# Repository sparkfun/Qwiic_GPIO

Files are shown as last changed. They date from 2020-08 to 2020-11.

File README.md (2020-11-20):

SparkFun Qwiic GPIO
=======================================

SparkFun Qwiic GPIO (https://cdn.sparkfun.com/assets/parts/1/5/9/9/3/17047-SparkFun_Qwiic_GPIO-01.jpg)

[*SparkFun Qwiic GPIO (DEV-17047)*](https://www.sparkfun.com/products/17047)

TCA9534 breakout board with Qwiic connectors and easy-to-use latch terminals; no longer screw wires into place! Use this board to add more GPIO pins to your system.

Repository Contents
-------------------

* **/Documents** - Contains datasheets and schematic.pdf
* **/Hardware** - Current .brd and .sch files for product
* **/Production** - Production panel files (.brd)

Documentation
-------------

* **[Hookup Guide](https://learn.sparkfun.com/tutorials/sparkfun-qwiic-gpio-hookup-guide)** - Hookup guide for The SparkFun Qwiic GPIO.
* **[Datasheet](https://cdn.sparkfun.com/assets/b/b/f/1/7/TCA9534.pdf) (TCA9534)** - Datasheet for the TCA9534.
* **[Qwiic Resource Page](https://www.sparkfun.com/qwiic)** - Resource guide for Qwiic.
* **[Arduino Library](https://github.com/sparkfun/SparkFun_Qwiic_GPIO_Library)** - Arduino Library for the SparkFun Qwiic GPIO.
* **[Python Package](https://github.com/sparkfun/Qwiic_GPIO_Py)** - Python package
* **[GitHub Hardware Repo](https://github.com/sparkfun/Qwiic_GPIO)** - Github Hardware Repo

License Information
-------------------

This product is _**open source**_!

Please review the LICENSE.md file for license information.

If you have any questions or concerns on licensing, please contact technical support on our [SparkFun forums](https://forum.sparkfun.com/viewforum.php?f=152).

Distributed as-is; no warranty is given.

- Your friends at SparkFun._

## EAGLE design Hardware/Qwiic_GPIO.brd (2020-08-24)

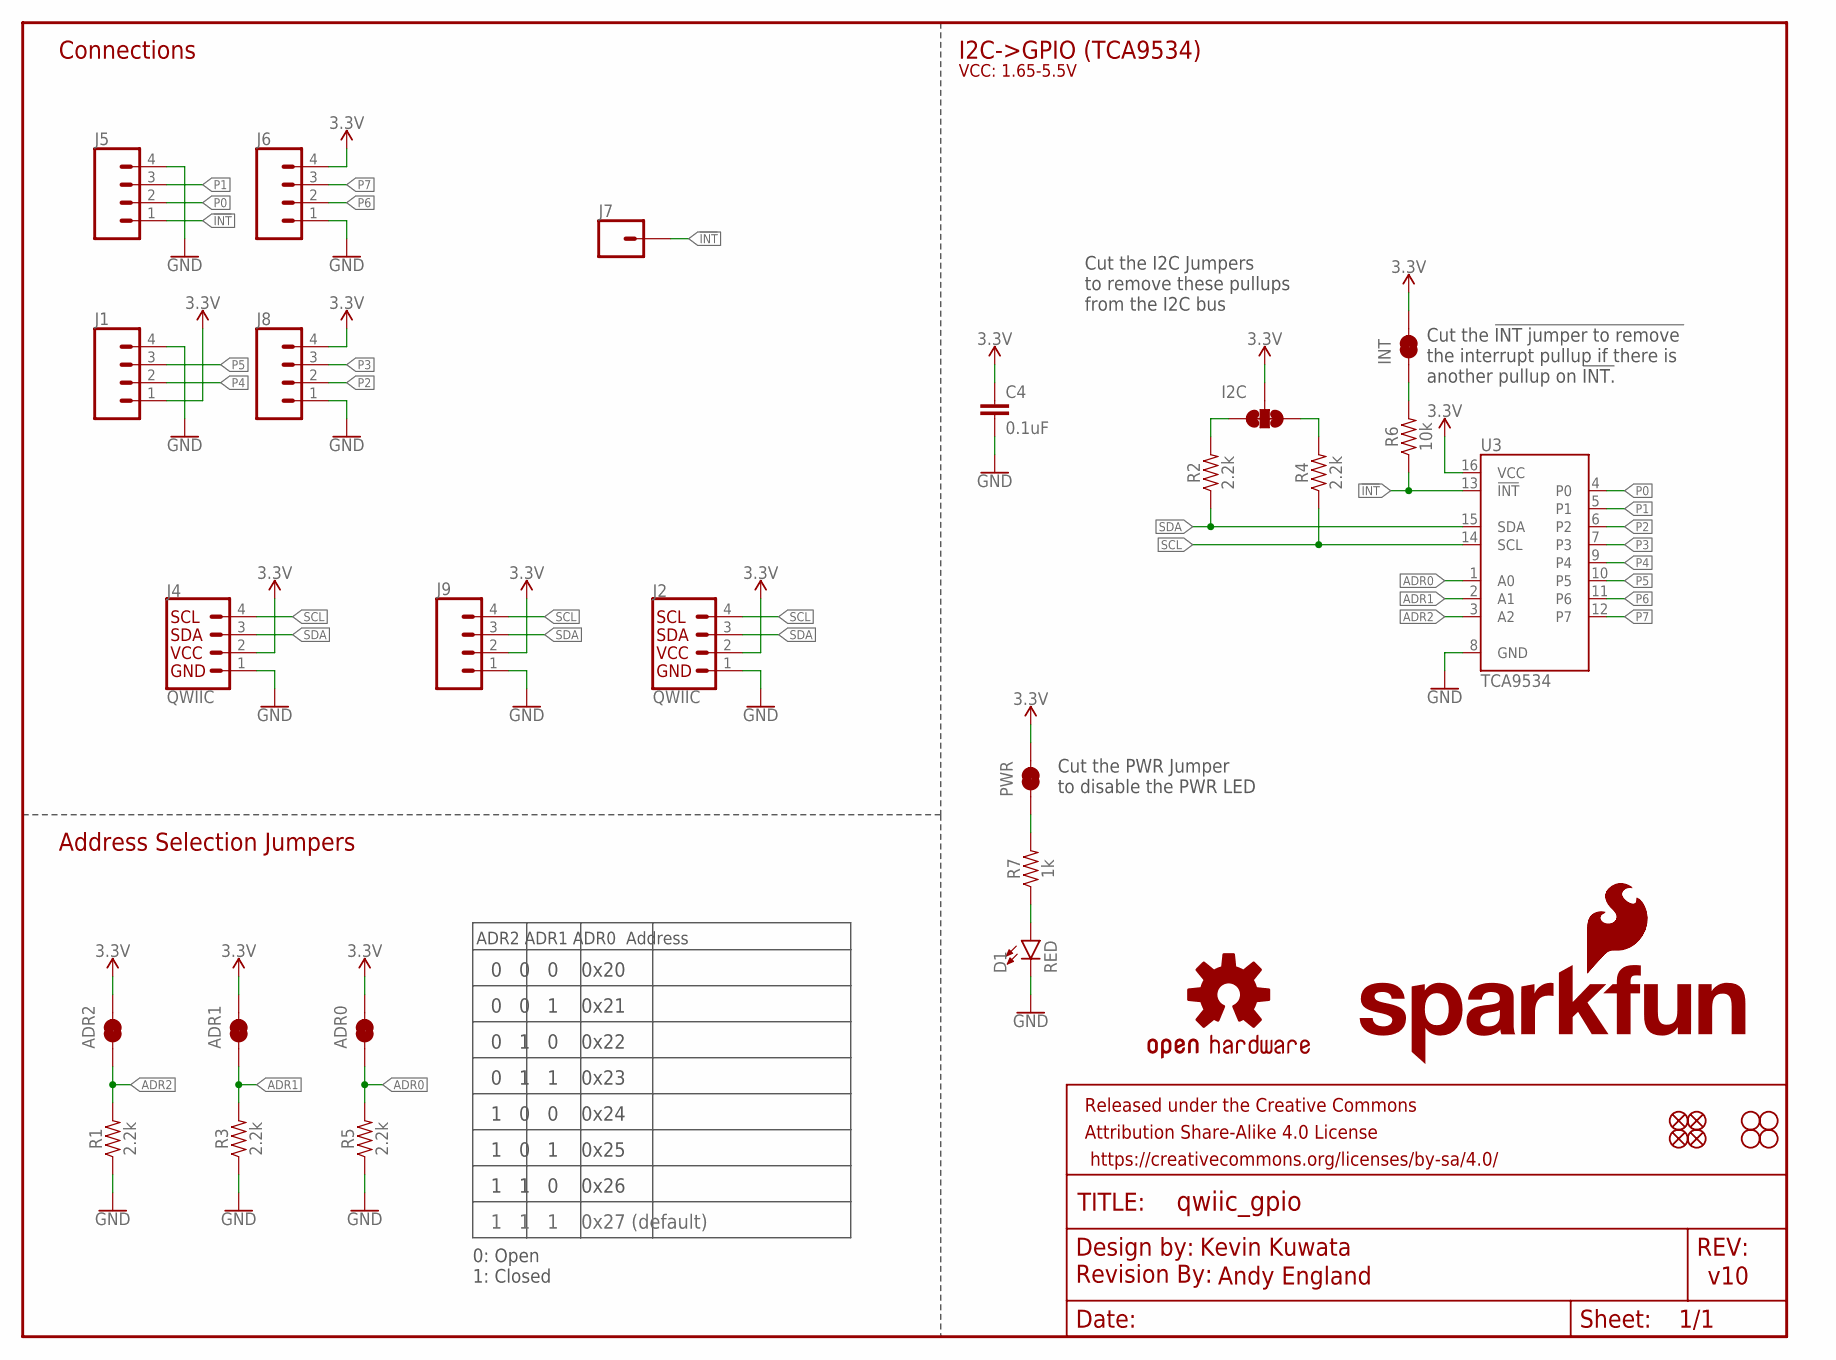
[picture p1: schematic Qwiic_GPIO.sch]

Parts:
ADR0, ADR1, ADR2: JUMPER-SMT_2_NC_TRACE_SILK; SMT-JUMPER_2_NC_TRACE_SILK
C4: 0.1uF; 0603
D1: RED; LED-0603
FD1, FD2: FIDUCIAL1X2; FIDUCIAL-1X2
FRAME1: FRAME-LETTER; CREATIVE_COMMONS
H1, H2: STAND-OFF
I2C: JUMPER-SMT_3_2-NC_TRACE_SILK; SMT-JUMPER_3_2-NC_TRACE_SILK
INT: JUMPER-SMT_2_NC_TRACE_SILK; SMT-JUMPER_2_NC_TRACE_SILK
J1, J5, J6, J8: CONN_04LATCH; LATCHTERMINAL-5MM-4
J2, J4: QWIIC; JST04_1MM_RA
J7: CONN_01PTH_NO_SILK_YES_STOP; 1X01_NO_SILK
J9: CONN_041X04_NO_SILK; 1X04_NO_SILK
JP2, JP6: FIDUCIAL1X2; FIDUCIAL-1X2
JP3, JP4: STAND-OFF
LOGO1: OSHW-LOGOMINI; OSHW-LOGO-MINI
LOGO2: REVISION
LOGO3: SFE_LOGO_NAME_FLAME.1_INCH; SFE_LOGO_NAME_FLAME_.1
LOGO4: SFE_LOGO_FLAME.2_INCH; SFE_LOGO_FLAME_.2
PWR: JUMPER-SMT_2_NC_TRACE_SILK; SMT-JUMPER_2_NC_TRACE_SILK
R1, R2, R3, R4, R5: 2.2k; 0603
R6: 10k; 0603
R7: 1k; 0603
U3: TCA9534; 16SOIC

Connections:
3.3V: ADR0.2, ADR1.2, ADR2.2, C4.1, I2C.2, INT.2, J1.1, J2.2, J4.2, J6.4, J8.4, J9.2, PWR.2, U3.16 (VCC)
!INT: J5.1, J7.1, R6.1, U3.13 (!INT)
ADR0: ADR0.1, R5.2, U3.1 (A0)
ADR1: ADR1.1, R3.2, U3.2 (A1)
ADR2: ADR2.1, R1.2, U3.3 (A2)
GND: C4.2, D1.C, J1.4, J2.1, J4.1, J5.4, J6.1, J8.1, J9.1, R1.1, R3.1, R5.1, U3.8 (GND)
unnamed: INT.1, R6.2
unnamed: D1.A, R7.1
unnamed: PWR.1, R7.2
P0: J5.2, U3.4 (P0)
P1: J5.3, U3.5 (P1)
P2: J8.2, U3.6 (P2)
P3: J8.3, U3.7 (P3)
P4: J1.2, U3.9 (P4)
P5: J1.3, U3.10 (P5)
P6: J6.2, U3.11 (P6)
P7: J6.3, U3.12 (P7)
SCL: J2.4, J4.4, J9.4, R4.1, U3.14 (SCL)
SCL_PU1: I2C.1, R2.2
SDA: J2.3, J4.3, J9.3, R2.1, U3.15 (SDA)
SDA_PU1: I2C.3, R4.2

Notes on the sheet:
Kevin Kuwata
v10
Address Selection Jumpers
ADR2 ADR1 ADR0 Address
0 0 0 0x20
0 0 1 0x21
0 1 0 0x22
0 1 1 0x23
1 0 0 0x24
1 0 1 0x25
1 1 0 0x26
1 1 1 0x27 (default)
0: Open 1: Closed
I2C->GPIO (TCA9534)
Connections
VCC: 1.65-5.5V
Andy England
Cut the !INT jumper to remove the interrupt pullup if there is another pullup on !INT.
Cut the I2C Jumpers to remove these pullups from the I2C bus
Cut the PWR Jumper to disable the PWR LED

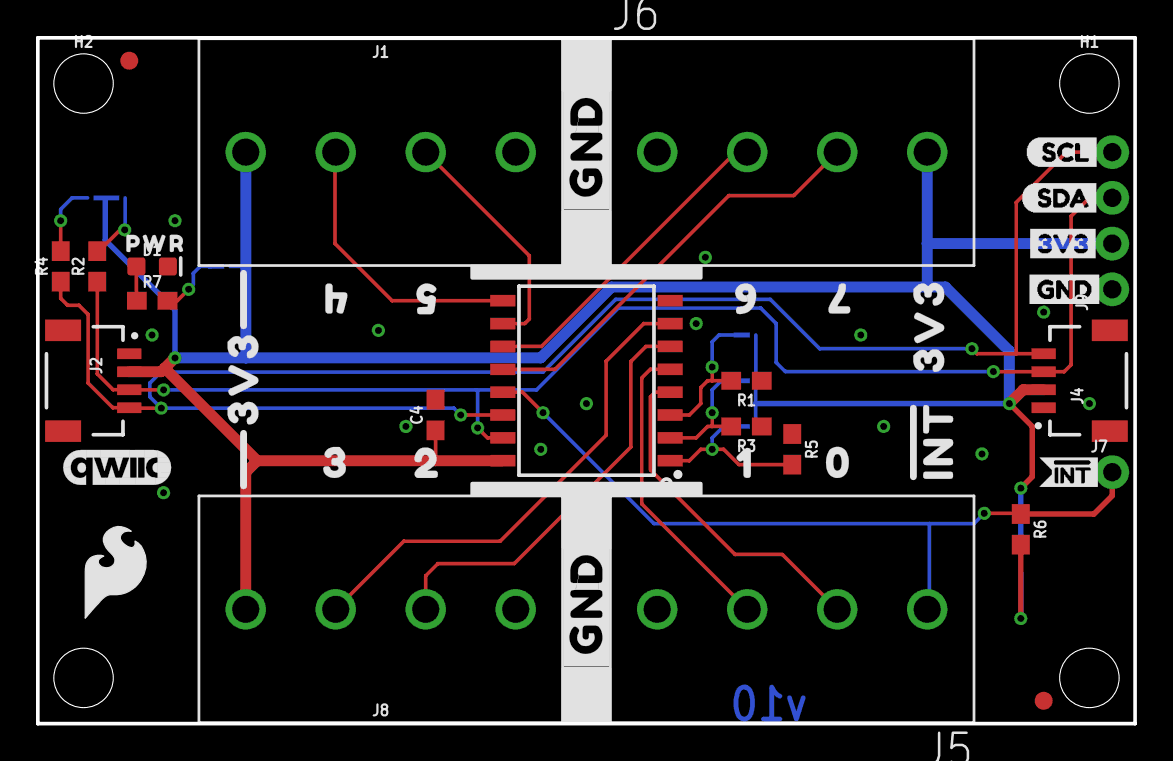
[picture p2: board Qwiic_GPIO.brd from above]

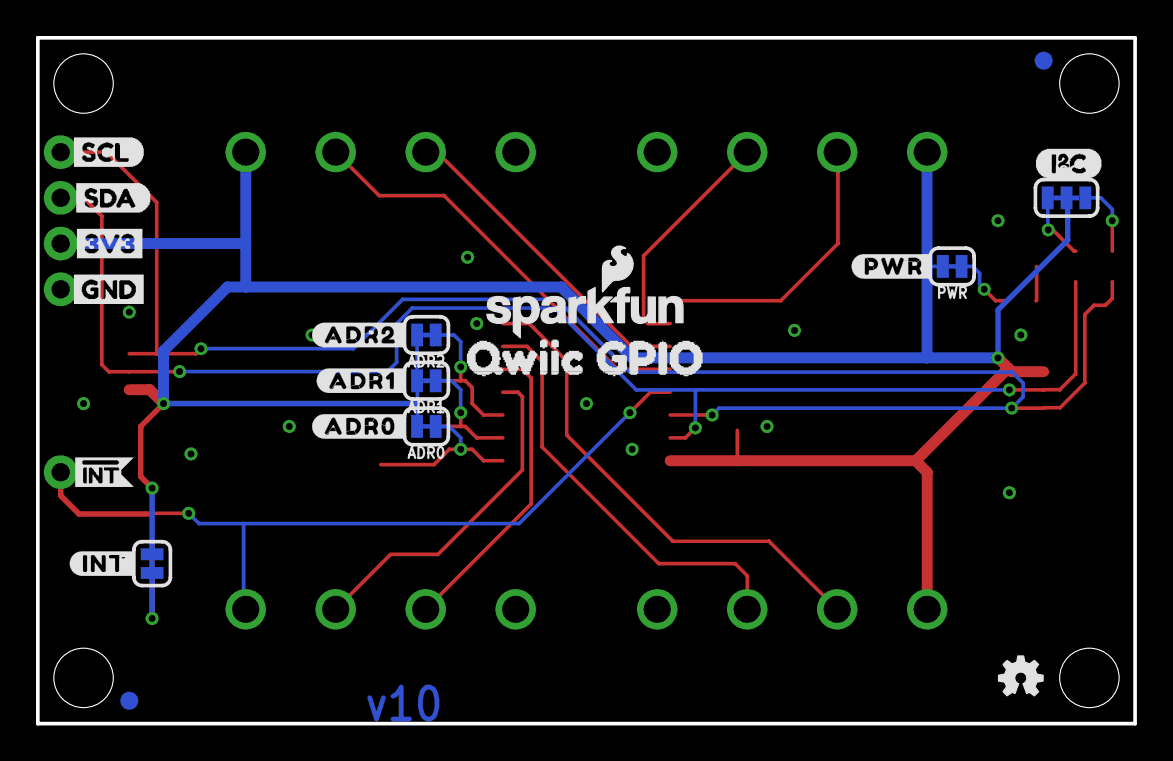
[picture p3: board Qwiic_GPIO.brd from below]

Board: 2 copper layers, 61.0 x 38.1 mm, 69 parts (22 on the bottom side), 21 nets.

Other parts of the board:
U$1: I2C
U$2: 20
U$3, U$26: 3V33
U$4: 30
U$5: #ADR1#0
U$6: 10
U$7, U$25: GND4
U$8: QWIIC_GPIO7
U$9: SCL6
U$10: SDA5
U$11: #ADR2#0
U$12: #INT#0
U$13, U$22, U$29: #INT0
U$14: 00
U$15: #ADR0#0
U$21: QWIIC_6MM
U$23: SCL0
U$24: SDA1
U$30, U$31: 3V30
U$32: 40
U$33: 50
U$34: PWR0
U$35: 60
U$37: 70
U$38, U$40: #GND#0
U$39: #PWR#0

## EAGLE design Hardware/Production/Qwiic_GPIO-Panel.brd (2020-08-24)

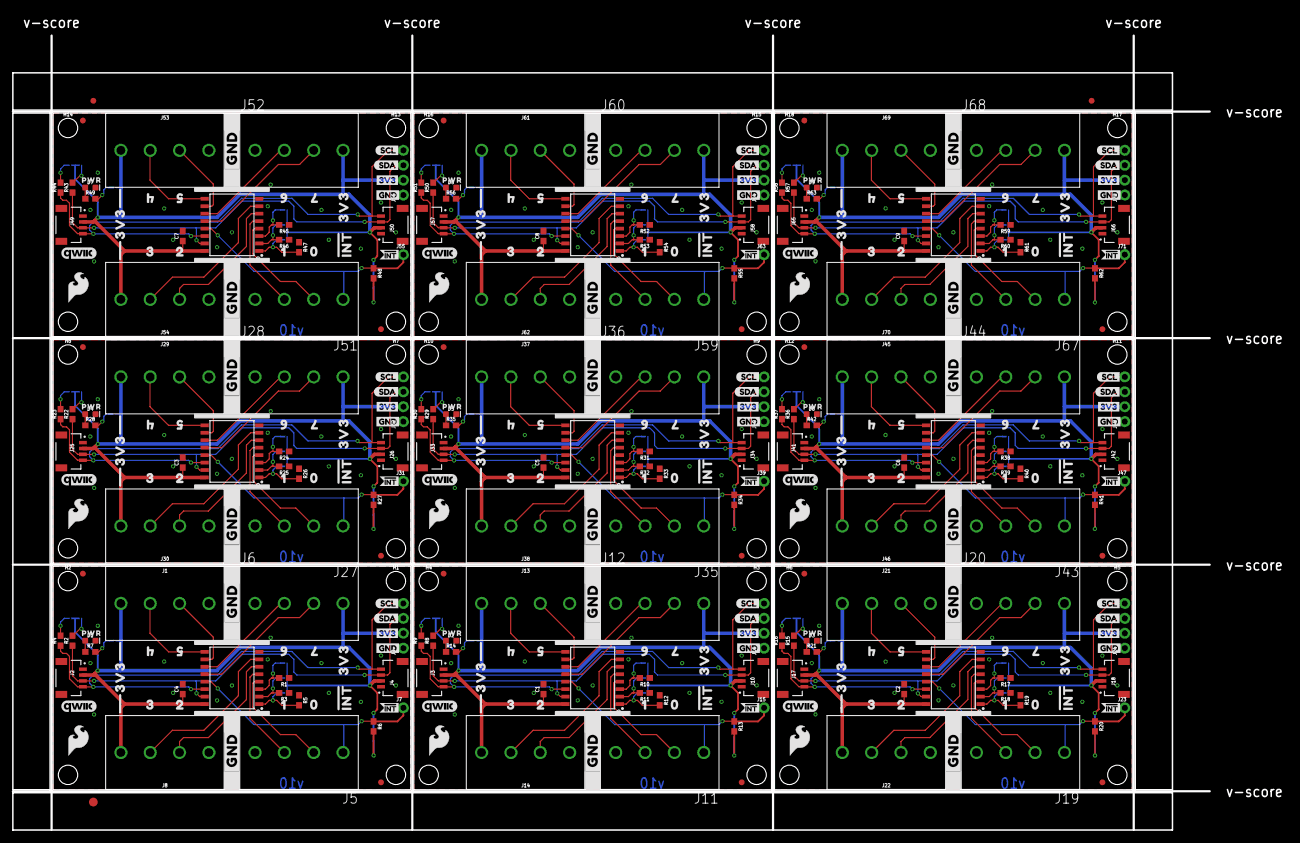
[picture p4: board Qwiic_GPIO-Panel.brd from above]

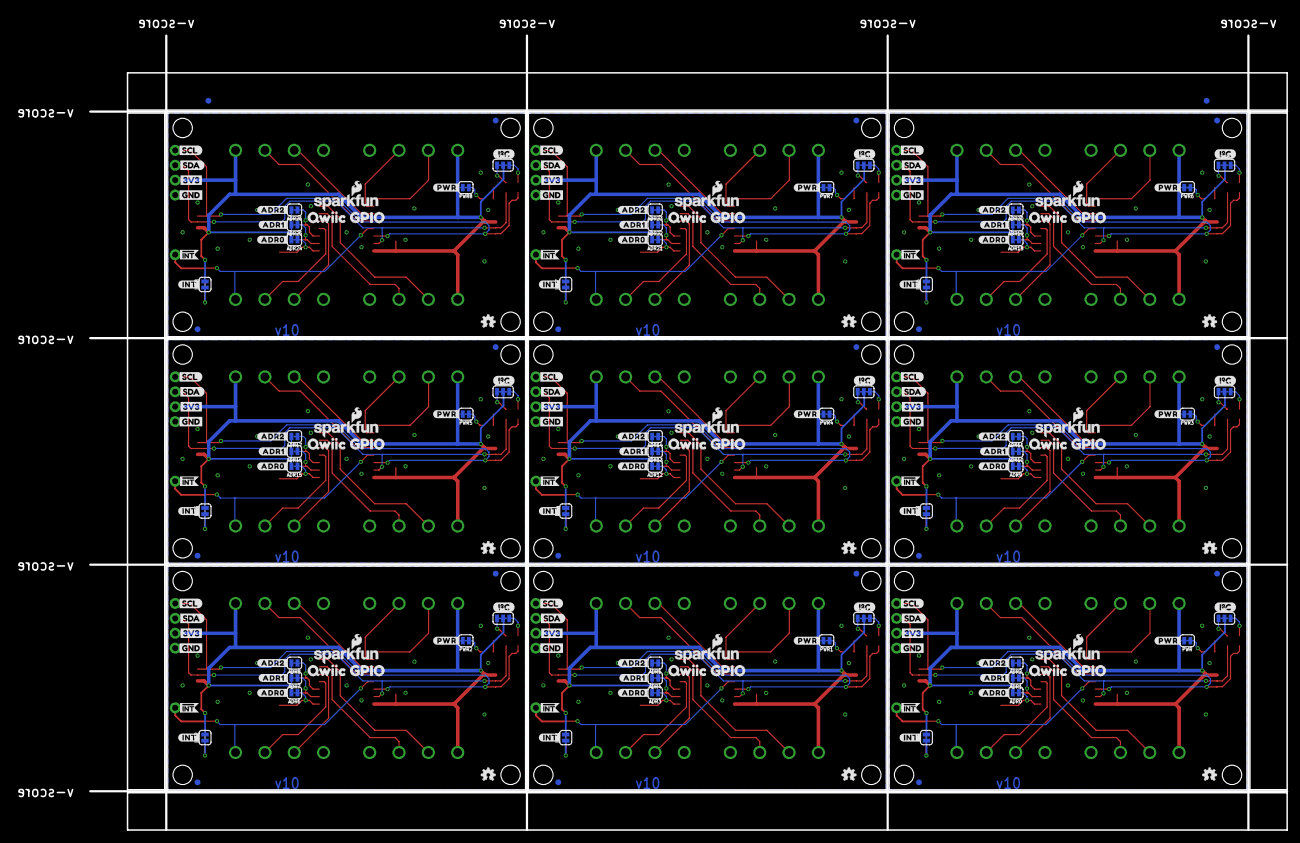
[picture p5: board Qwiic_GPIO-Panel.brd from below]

Board: 2 copper layers, 204.0 x 135.4 mm, 626 parts (200 on the bottom side), 189 nets.

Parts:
ADR0, ADR1, ADR2, ADR3, ADR4, ADR5, ADR6, ADR7, ADR8, ADR9, ADR10, ADR11, ADR12, ADR13, ADR14, ADR15, ADR16, ADR17, ADR18, ADR19, ADR20, ADR21, ADR22, ADR23, ADR24, ADR25, ADR26: JUMPER-SMT_2_NC_TRACE_SILK; SMT-JUMPER_2_NC_TRACE_SILK
C1, C2, C3, C4, C5, C6, C7, C8, C9: 0.1uF; 0603
D1, D2, D3, D4, D5, D6, D7, D8, D9: RED; LED-0603
E$1, E$2, E$3, E$4: FIDUCIAL-1X2
E$5: FIDUCIAL-1.5X3
FD1, FD2, FD3, FD4, FD5, FD6, FD7, FD8, FD9, FD10, FD11, FD12, FD13, FD14, FD15, FD16, FD17, FD18: FIDUCIAL1X2; FIDUCIAL-1X2
FRAME1, FRAME2, FRAME3, FRAME4, FRAME5, FRAME6, FRAME7, FRAME8, FRAME9: FRAME-LETTER; CREATIVE_COMMONS
H1, H2, H3, H4, H5, H6, H7, H8, H9, H10, H11, H12, H13, H14, H15, H16, H17, H18: STAND-OFF
I2C, I2C1, I2C2, I2C3, I2C4, I2C5, I2C6, I2C7, I2C8: JUMPER-SMT_3_2-NC_TRACE_SILK; SMT-JUMPER_3_2-NC_TRACE_SILK
INT, INT1, INT2, INT3, INT4, INT5, INT6, INT7, INT8: JUMPER-SMT_2_NC_TRACE_SILK; SMT-JUMPER_2_NC_TRACE_SILK
J1, J5, J6, J8, J11, J12, J13, J14, J19, J20, J21, J22, J27, J28, J29, J30, J35, J36, J37, J38, J43, J44, J45, J46, J51, J52, J53, J54, J59, J60, J61, J62, J67, J68, J69, J70: LATCHTERMINAL-5MM-4
J2, J3, J4, J10, J17, J18, J25, J26, J33, J34, J41, J42, J49, J50, J57, J58, J65, J66: QWIIC; JST04_1MM_RA
J7, J15, J23, J31, J39, J47, J55, J63, J71: 1X01_NO_SILK
J9, J16, J24, J32, J40, J48, J56, J64, J72: 1X04_NO_SILK
JP1, JP3, JP4, JP5, JP9, JP10, JP13, JP14, JP17, JP18, JP21, JP22, JP25, JP26, JP29, JP30, JP33, JP34: STAND-OFF
JP2, JP6, JP7, JP8, JP11, JP12, JP15, JP16, JP19, JP20, JP23, JP24, JP27, JP28, JP31, JP32, JP35, JP36: FIDUCIAL1X2; FIDUCIAL-1X2
LOGO1, LOGO5, LOGO9, LOGO13, LOGO17, LOGO21, LOGO25, LOGO29, LOGO33: OSHW-LOGOMINI; OSHW-LOGO-MINI
LOGO2, LOGO6, LOGO10, LOGO14, LOGO18, LOGO22, LOGO26, LOGO30, LOGO34: REVISION
LOGO3, LOGO7, LOGO11, LOGO15, LOGO19, LOGO23, LOGO27, LOGO31, LOGO35: SFE_LOGO_NAME_FLAME.1_INCH; SFE_LOGO_NAME_FLAME_.1
LOGO4, LOGO8, LOGO12, LOGO16, LOGO20, LOGO24, LOGO28, LOGO32, LOGO36: SFE_LOGO_FLAME.2_INCH; SFE_LOGO_FLAME_.2
PWR, PWR1, PWR2, PWR3, PWR4, PWR5, PWR6, PWR7, PWR8: JUMPER-SMT_2_NC_TRACE_SILK; SMT-JUMPER_2_NC_TRACE_SILK
R1, R2, R3, R4, R5, R8, R9, R10, R11, R12, R15, R16, R17, R18, R19, R22, R23, R24, R25, R26, R29, R30, R31, R32, R33, R36, R37, R38, R39, R40, R43, R44, R45, R46, R47, R50, R51, R52, R53, R54, R57, R58, R59, R60, R61: 2.2k; 0603
R6, R13, R20, R27, R34, R41, R48, R55, R62: 10k; 0603
R7, R14, R21, R28, R35, R42, R49, R56, R63: 1k; 0603
U1, U2, U3, U4, U5, U6, U7, U8, U9: TCA9534; 16SOIC
U$1, U$45, U$77, U$109, U$141, U$173, U$205, U$237, U$269: I2C
U$2, U$49, U$81, U$113, U$145, U$177, U$209, U$241, U$273: 20
U$3, U$16, U$26, U$42, U$65, U$74, U$97, U$106, U$129, U$138, U$161, U$170, U$193, U$202, U$225, U$234, U$257, U$266: 3V33
U$4, U$50, U$82, U$114, U$146, U$178, U$210, U$242, U$274: 30
U$5, U$63, U$95, U$127, U$159, U$191, U$223, U$255, U$287: #ADR1#0
U$6, U$51, U$83, U$115, U$147, U$179, U$211, U$243, U$275: 10
U$7, U$17, U$25, U$41, U$66, U$73, U$98, U$105, U$130, U$137, U$162, U$169, U$194, U$201, U$226, U$233, U$258, U$265: GND4
U$8, U$18, U$67, U$99, U$131, U$163, U$195, U$227, U$259: QWIIC_GPIO7
U$9, U$19, U$68, U$100, U$132, U$164, U$196, U$228, U$260: SCL6
U$10, U$20, U$69, U$101, U$133, U$165, U$197, U$229, U$261: SDA5
U$11, U$64, U$96, U$128, U$160, U$192, U$224, U$256, U$288: #ADR2#0
U$12, U$47, U$79, U$111, U$143, U$175, U$207, U$239, U$271: #INT#0
U$13, U$22, U$29, U$43, U$44, U$53, U$75, U$76, U$85, U$107, U$108, U$117, U$139, U$140, U$149, U$171, U$172, U$181, U$203, U$204, U$213, U$235, U$236, U$245, U$267, U$268, U$277: #INT0
U$14, U$52, U$84, U$116, U$148, U$180, U$212, U$244, U$276: 00
U$15, U$62, U$94, U$126, U$158, U$190, U$222, U$254, U$286: #ADR0#0
U$21, U$27, U$70, U$102, U$134, U$166, U$198, U$230, U$262: QWIIC_6MM
U$23, U$28, U$71, U$103, U$135, U$167, U$199, U$231, U$263: SCL0
U$24, U$36, U$72, U$104, U$136, U$168, U$200, U$232, U$264: SDA1
U$30, U$31, U$54, U$55, U$86, U$87, U$118, U$119, U$150, U$151, U$182, U$183, U$214, U$215, U$246, U$247, U$278, U$279: 3V30
U$32, U$56, U$88, U$120, U$152, U$184, U$216, U$248, U$280: 40
U$33, U$57, U$89, U$121, U$153, U$185, U$217, U$249, U$281: 50
U$34, U$46, U$78, U$110, U$142, U$174, U$206, U$238, U$270: PWR0
U$35, U$58, U$90, U$122, U$154, U$186, U$218, U$250, U$282: 60
U$37, U$59, U$91, U$123, U$155, U$187, U$219, U$251, U$283: 70
U$38, U$40, U$60, U$61, U$92, U$93, U$124, U$125, U$156, U$157, U$188, U$189, U$220, U$221, U$252, U$253, U$284, U$285: #GND#0
U$39, U$48, U$80, U$112, U$144, U$176, U$208, U$240, U$272: #PWR#0

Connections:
3.3V: ADR0.2, ADR1.2, ADR2.2, C4.1, I2C.2, INT.2, J1.1, J2.2, J4.2, J6.4, J8.4, J9.2, PWR.2, U3.16
3.3V1: ADR3.2, ADR4.2, ADR5.2, C1.1, I2C1.2, INT1.2, J3.2, J10.2, J12.4, J13.1, J14.4, J16.2, PWR1.2, U1.16
3.3V2: ADR6.2, ADR7.2, ADR8.2, C2.1, I2C2.2, INT2.2, J17.2, J18.2, J20.4, J21.1, J22.4, J24.2, PWR2.2, U2.16
3.3V3: ADR9.2, ADR10.2, ADR11.2, C3.1, I2C3.2, INT3.2, J25.2, J26.2, J28.4, J29.1, J30.4, J32.2, PWR3.2, U4.16
3.3V4: ADR12.2, ADR13.2, ADR14.2, C5.1, I2C4.2, INT4.2, J33.2, J34.2, J36.4, J37.1, J38.4, J40.2, PWR4.2, U5.16
3.3V5: ADR15.2, ADR16.2, ADR17.2, C6.1, I2C5.2, INT5.2, J41.2, J42.2, J44.4, J45.1, J46.4, J48.2, PWR5.2, U6.16
3.3V6: ADR18.2, ADR19.2, ADR20.2, C7.1, I2C6.2, INT6.2, J49.2, J50.2, J52.4, J53.1, J54.4, J56.2, PWR6.2, U7.16
3.3V7: ADR21.2, ADR22.2, ADR23.2, C8.1, I2C7.2, INT7.2, J57.2, J58.2, J60.4, J61.1, J62.4, J64.2, PWR7.2, U8.16
3.3V8: ADR24.2, ADR25.2, ADR26.2, C9.1, I2C8.2, INT8.2, J65.2, J66.2, J68.4, J69.1, J70.4, J72.2, PWR8.2, U9.16
!INT: J5.1, J7.1, R6.1, U3.13
!INT1: J11.1, J15.1, R13.1, U1.13
!INT2: J19.1, J23.1, R20.1, U2.13
!INT3: J27.1, J31.1, R27.1, U4.13
!INT4: J35.1, J39.1, R34.1, U5.13
!INT5: J43.1, J47.1, R41.1, U6.13
!INT6: J51.1, J55.1, R48.1, U7.13
!INT7: J59.1, J63.1, R55.1, U8.13
!INT8: J67.1, J71.1, R62.1, U9.13
ADR0: ADR0.1, R5.2, U3.1
ADR1: ADR1.1, R3.2, U3.2
ADR2: ADR2.1, R1.2, U3.3
ADR3: ADR3.1, R12.2, U1.1
ADR4: ADR4.1, R11.2, U1.2
ADR5: ADR5.1, R10.2, U1.3
ADR6: ADR6.1, R19.2, U2.1
ADR7: ADR7.1, R18.2, U2.2
ADR8: ADR8.1, R17.2, U2.3
ADR9: ADR9.1, R26.2, U4.1
ADR10: ADR10.1, R25.2, U4.2
ADR11: ADR11.1, R24.2, U4.3
ADR12: ADR12.1, R33.2, U5.1
ADR13: ADR13.1, R32.2, U5.2
ADR14: ADR14.1, R31.2, U5.3
ADR15: ADR15.1, R40.2, U6.1
ADR16: ADR16.1, R39.2, U6.2
ADR17: ADR17.1, R38.2, U6.3
ADR18: ADR18.1, R47.2, U7.1
ADR19: ADR19.1, R46.2, U7.2
ADR20: ADR20.1, R45.2, U7.3
ADR21: ADR21.1, R54.2, U8.1
ADR22: ADR22.1, R53.2, U8.2
ADR23: ADR23.1, R52.2, U8.3
ADR24: ADR24.1, R61.2, U9.1
ADR25: ADR25.1, R60.2, U9.2
ADR26: ADR26.1, R59.2, U9.3
GND: C4.2, D1.C, J1.4, J2.1, J4.1, J5.4, J6.1, J8.1, J9.1, R1.1, R3.1, R5.1, U3.8
GND1: C1.2, D2.C, J3.1, J10.1, J11.4, J12.1, J13.4, J14.1, J16.1, R10.1, R11.1, R12.1, U1.8
GND2: C2.2, D3.C, J17.1, J18.1, J19.4, J20.1, J21.4, J22.1, J24.1, R17.1, R18.1, R19.1, U2.8
GND3: C3.2, D4.C, J25.1, J26.1, J27.4, J28.1, J29.4, J30.1, J32.1, R24.1, R25.1, R26.1, U4.8
GND4: C5.2, D5.C, J33.1, J34.1, J35.4, J36.1, J37.4, J38.1, J40.1, R31.1, R32.1, R33.1, U5.8
GND5: C6.2, D6.C, J41.1, J42.1, J43.4, J44.1, J45.4, J46.1, J48.1, R38.1, R39.1, R40.1, U6.8
GND6: C7.2, D7.C, J49.1, J50.1, J51.4, J52.1, J53.4, J54.1, J56.1, R45.1, R46.1, R47.1, U7.8
GND7: C8.2, D8.C, J57.1, J58.1, J59.4, J60.1, J61.4, J62.1, J64.1, R52.1, R53.1, R54.1, U8.8
GND8: C9.2, D9.C, J65.1, J66.1, J67.4, J68.1, J69.4, J70.1, J72.1, R59.1, R60.1, R61.1, U9.8
unnamed: INT.1, R6.2
unnamed: D1.A, R7.1
unnamed: PWR.1, R7.2
unnamed: INT1.1, R13.2
unnamed: D2.A, R14.1
unnamed: PWR1.1, R14.2
unnamed: INT2.1, R20.2
unnamed: D3.A, R21.1
unnamed: PWR2.1, R21.2
unnamed: INT3.1, R27.2
unnamed: D4.A, R28.1
unnamed: PWR3.1, R28.2
unnamed: INT4.1, R34.2
unnamed: D5.A, R35.1
unnamed: PWR4.1, R35.2
unnamed: INT5.1, R41.2
unnamed: D6.A, R42.1
unnamed: PWR5.1, R42.2
unnamed: INT6.1, R48.2
unnamed: D7.A, R49.1
unnamed: PWR6.1, R49.2
unnamed: INT7.1, R55.2
unnamed: D8.A, R56.1
unnamed: PWR7.1, R56.2
unnamed: INT8.1, R62.2
unnamed: D9.A, R63.1
unnamed: PWR8.1, R63.2
P0: J5.2, U3.4
P1: J5.3, U3.5
P2: J8.2, U3.6
P3: J8.3, U3.7
P4: J1.2, U3.9
P5: J1.3, U3.10
P6: J6.2, U3.11
P7: J6.3, U3.12
P8: J11.2, U1.4
P9: J14.2, U1.6
P10: J14.3, U1.7
P11: J11.3, U1.5
P12: J13.2, U1.9
P13: J13.3, U1.10
P14: J12.2, U1.11
P15: J12.3, U1.12
P16: J19.2, U2.4
P17: J22.2, U2.6
P18: J22.3, U2.7
P19: J19.3, U2.5
P20: J21.2, U2.9
P21: J21.3, U2.10
P22: J20.2, U2.11
P23: J20.3, U2.12
P24: J27.2, U4.4
P25: J30.2, U4.6
P26: J30.3, U4.7
P27: J27.3, U4.5
P28: J29.2, U4.9
P29: J29.3, U4.10
P30: J28.2, U4.11
P31: J28.3, U4.12
P32: J35.2, U5.4
P33: J38.2, U5.6
P34: J38.3, U5.7
P35: J35.3, U5.5
P36: J37.2, U5.9
P37: J37.3, U5.10
P38: J36.2, U5.11
P39: J36.3, U5.12
P40: J43.2, U6.4
P41: J46.2, U6.6
P42: J46.3, U6.7
P43: J43.3, U6.5
P44: J45.2, U6.9
P45: J45.3, U6.10
P46: J44.2, U6.11
P47: J44.3, U6.12
P48: J51.2, U7.4
P49: J54.2, U7.6
P50: J54.3, U7.7
P51: J51.3, U7.5
P52: J53.2, U7.9
P53: J53.3, U7.10
P54: J52.2, U7.11
P55: J52.3, U7.12
P56: J59.2, U8.4
P57: J62.2, U8.6
P58: J62.3, U8.7
P59: J59.3, U8.5
P60: J61.2, U8.9
P61: J61.3, U8.10
P62: J60.2, U8.11
P63: J60.3, U8.12
P64: J67.2, U9.4
P65: J70.2, U9.6
P66: J70.3, U9.7
P67: J67.3, U9.5
P68: J69.2, U9.9
P69: J69.3, U9.10
P70: J68.2, U9.11
P71: J68.3, U9.12
SCL: J2.4, J4.4, J9.4, R4.1, U3.14
SCL1: J3.4, J10.4, J16.4, R9.1, U1.14
SCL2: J17.4, J18.4, J24.4, R16.1, U2.14
SCL3: J25.4, J26.4, J32.4, R23.1, U4.14
SCL4: J33.4, J34.4, J40.4, R30.1, U5.14
SCL5: J41.4, J42.4, J48.4, R37.1, U6.14
SCL6: J49.4, J50.4, J56.4, R44.1, U7.14
SCL7: J57.4, J58.4, J64.4, R51.1, U8.14
SCL8: J65.4, J66.4, J72.4, R58.1, U9.14
SCL_PU1: I2C.1, R2.2
SCL_PU2: I2C1.1, R8.2
SCL_PU3: I2C2.1, R15.2
SCL_PU4: I2C3.1, R22.2
SCL_PU5: I2C4.1, R29.2
SCL_PU6: I2C5.1, R36.2
SCL_PU7: I2C6.1, R43.2
SCL_PU8: I2C7.1, R50.2
SCL_PU9: I2C8.1, R57.2
SDA: J2.3, J4.3, J9.3, R2.1, U3.15
SDA1: J3.3, J10.3, J16.3, R8.1, U1.15
SDA2: J17.3, J18.3, J24.3, R15.1, U2.15
SDA3: J25.3, J26.3, J32.3, R22.1, U4.15
SDA4: J33.3, J34.3, J40.3, R29.1, U5.15
SDA5: J41.3, J42.3, J48.3, R36.1, U6.15
SDA6: J49.3, J50.3, J56.3, R43.1, U7.15
SDA7: J57.3, J58.3, J64.3, R50.1, U8.15
SDA8: J65.3, J66.3, J72.3, R57.1, U9.15
SDA_PU1: I2C.3, R4.2
SDA_PU2: I2C1.3, R9.2
SDA_PU3: I2C2.3, R16.2
SDA_PU4: I2C3.3, R23.2
SDA_PU5: I2C4.3, R30.2
SDA_PU6: I2C5.3, R37.2
SDA_PU7: I2C6.3, R44.2
SDA_PU8: I2C7.3, R51.2
SDA_PU9: I2C8.3, R58.2

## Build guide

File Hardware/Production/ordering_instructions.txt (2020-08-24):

panel size, 198x123mm
PCB thickness, 1.6mm
number of layers, 2
soldermask color, Red
silkscreen color, White
oz copper, 1oz
finish, HASL lead free
stencils, top
pcs per panel, 9
min trace width, 0.2032mm / 0.0080in
min drill size, 0.3810mm / 0.0150in

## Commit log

2020-08-06 Updating address jumper note
    [Qwiic_GPIO.sch]
2020-08-10 adding rest of GPIO pins
    [Qwiic_GPIO.brd, Qwiic_GPIO.sch]
2020-08-20 post checklist changes
    [Qwiic_GPIO.brd, Qwiic_GPIO.sch]
2020-08-20 moving text on schematic
    [Qwiic_GPIO.sch]
2020-08-24 uploading panel
    [Qwiic_GPIO-Panel.GBL, Qwiic_GPIO-Panel.GBO, Qwiic_GPIO-Panel.GBS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]
2020-08-27 pushing panel
    [Qwiic_GPIO-Panel.GBL, Qwiic_GPIO-Panel.GBO, Qwiic_GPIO-Panel.GBP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]

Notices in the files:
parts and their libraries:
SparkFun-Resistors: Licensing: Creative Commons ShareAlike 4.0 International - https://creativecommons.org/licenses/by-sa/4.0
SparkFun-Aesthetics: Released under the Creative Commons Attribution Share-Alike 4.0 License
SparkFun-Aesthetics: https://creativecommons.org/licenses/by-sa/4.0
